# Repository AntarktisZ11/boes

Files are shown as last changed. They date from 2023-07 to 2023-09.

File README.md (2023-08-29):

# What is this?

This is Bamses Øhlhäfvarstoppur also called Bøs.

TODO Desc. the rules of häfv.

# Why is this?

TODO

# How to build Bøs (Bamses Øhlhäfvarstoppur)

TODO

## Hardware prerequisites

[List of components](./Hardware.md)

Rough cost estimate: 1000-800kr

<details>
<summary>Pico RGB matrix pinout</summary>
<br>
TODO add pinout

</details>

### Main PCB

[Schematic PDF](./docs/pcb-boes-main/boes-schematic.pdf)

[CSV BoM](./docs/pcb-boes-main/BoM/boes-bom.csv)

[Interactive BoM](./docs/pcb-boes-main/BoM/boes-ibom.html) (Download and view in browser.)

#### Top and bottom view of PCB

PCB top-view SVG
PCB bottom-view SVG

### USB-C Power distribution PCB

[Schematic PDF](./docs/pcb-boes-usb-c/boes_usb-c-schematic.pdf)

[CSV BoM](./docs/pcb-boes-usb-c/BoM/boes_usb-c-bom.csv)

[Interactive BoM](./docs/pcb-boes-usb-c/BoM/boes_usb-c-ibom.html) (Download and view in browser.)

#### Top and bottom view of PCB

PCB top-view SVG
PCB bottom-view SVG

### Sensor PCB

[Schematic PDF](./docs/pcb-boes-sensor/boes_sensor-schematic.pdf)

[CSV BoM](./docs/pcb-boes-sensor/BoM/boes_sensor-bom.csv)

[Interactive BoM](./docs/pcb-boes-sensor/BoM/boes_sensor-ibom.html) (Download and view in browser.)

#### Top and bottom view of PCB

PCB top-view SVG
PCB bottom-view SVG

## Software prerequisites

The following tools and libraries are required to compile and flash the Pico.

- Arduino CLI tool (or Arduino IDE, whatever works)
- [Raspberry Pi Pico Arduino core](https://github.com/earlephilhower/arduino-pico)
- Adafruit and Arduino libraries (see below)

## Linux guide

Install Pico Arduino core (if not already prepared):

```bash
# Initialize arduino-cli
arduino-cli config init

# Add Pico url to additional_urls like this:
additional_urls: [https://github.com/earlephilhower/arduino-pico/releases/download/global/package_rp2040_index.json]

# Update index to download rp2040 config
arduino-cli core update-index

# Download Pico cores
arduino-cli core install rp2040:rp204
```

Install the required libraries:

```bash
# Note: 'arduino-cli lib install <library>' installs <library>
# and all its dependencies.

# Adafruit library required to driver the led matrix.
arduino-cli lib install "Adafruit Protomatter"

# Protothread / simulated threads in software to schedule
# timer, display and button controllers.
arduino-cli lib install "ArduinoThread"
```

## Compiling and uploading binary

After the prerequisites are satisfied you should be able to compile and upload the binary to the Pico.

```bash
# Compile and upload binary.
# (Note: For me <serial> was set to /dev/ttyACM0)
arduino-cli compile -u -p <serial> -b rp2040:rp2040:rpipicow display/display.ino
```

# Future improvements

- Separate code into thread classes (e.g. display and web server handling in their own respective class)
- Config file handling for constants/delays/logo (USB mass storage) when plugging the cable (also allow uploading configs on web server site?)
- HTML/CSS file handling (USB mass storage).. not the crude http response way that is currently implemented

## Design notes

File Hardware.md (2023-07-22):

Needed hardware is as follows.

- Raspberry Pi Pico or Pico W
- 3x buttons
    - Start
    - Stop
    - Reset
- Speaker/Buzzer (Has to be loud enough)
- 2x Vibration sensors
    - GX-16-3 connector
    - Sensitivity potentiometer
    - Sensor element (piezo or microphone)
    - May need amplifier.
- USB-C connector, 5V / 2.5A
- IDC-16 connector
- Display power connector/screw terminal
- Display, P*x.x* HUB75 RGB LED
    - Note: P*x.x* is the pixel pitch. P2.5 for desktop (160mm x 80mm), P5 for large screen (320mm x 160mm).

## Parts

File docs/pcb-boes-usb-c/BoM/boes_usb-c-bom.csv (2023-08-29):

Part | Value | Footprint | References | Quantity Per PCB | Farnell Nr | Datasheet
USB_C_Receptacle_USB2.0 | USB_C_Receptacle_USB2.0 | USB_C_Receptacle_GCT_USB4105-xx-A_16P_TopMnt_Horizontal | J1 | 1 |  | https://www.usb.org/sites/default/files/documents/usb_type-c.zip
R | 5k1 | R_0603_1608Metric | R1 R2 | 2 |  | ~

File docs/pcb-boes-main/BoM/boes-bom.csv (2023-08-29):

Part | Value | Footprint | References | Quantity Per PCB | Farnell Nr | Datasheet
Buzzer | Buzzer |  | BZ1 | 1 |  | https://www.farnell.com/datasheets/1504043.pdf
D_Schottky | D_Schottky | D_SMA-SMB_Universal_Handsoldering | D1 | 1 |  | ~
Screw_Terminal_01x02 | +5V External | TerminalBlock_Phoenix_MKDS-1,5-2-5.08_1x02_P5.08mm_Horizontal | J9 | 1 |  | ~
Conn_02x08_Odd_Even | HUB75 Display ctrl | IDC-Header_2x08_P2.54mm_Vertical | J10 | 1 |  | ~
Conn_01x03 | Pot_J | JST_XH_B3B-XH-A_1x03_P2.50mm_Vertical | J4 J6 J7 P4 | 4 |  | ~
Conn_01x02 | SW_A | JST_XH_B2B-XH-A_1x02_P2.50mm_Vertical | J1 J2 J3 J8 P1 P2 P3 P8 | 8 |  | ~
2N7000 | 2N7000 | SOT-23 | Q1 | 1 |  | https://www.vishay.com/docs/70226/70226.pdf
R | R | R_0603_1608Metric | R2 | 1 |  | ~
R | 10k | R_0603_1608Metric | R1 | 1 |  | ~
R_Potentiometer | 10k |  | RV1 | 1 |  | ~
SW_Push | Reset |  | SW3 | 1 |  | ~
SW_Push | Start |  | SW1 | 1 |  | ~
SW_Push | Stop |  | SW2 | 1 |  | ~
PicoW | PicoW | RPi_PicoW_SMD_TH | U1 | 1 |  | https://datasheets.raspberrypi.com/picow/pico-w-datasheet.pdf

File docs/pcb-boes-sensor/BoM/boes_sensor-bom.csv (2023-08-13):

Part | Value | Footprint | References | Quantity Per PCB | Farnell Nr | Datasheet
C | 100n | C_0603_1608Metric | C1 C2 C4 | 3 |  | ~
C | 1u | C_0603_1608Metric | C3 | 1 |  | ~
D | 1N4148 | D_MiniMELF | D2 | 1 |  | ~
BAV99 | BAV99 | SOT-23 | D1 | 1 |  | https://assets.nexperia.com/documents/data-sheet/BAV99_SER.pdf
R | R | R_0603_1608Metric | R1 R2 | 2 |  | ~
R | 100k | R_0603_1608Metric | R4 | 1 |  | ~
R_Variable | R_Variable | R_0603_1608Metric | R3 | 1 |  | ~
LM358 | LM358 | SOIC-8_3.9x4.9mm_P1.27mm | U1 | 1 |  | http://www.ti.com/lit/ds/symlink/lm2904-n.pdf
Crystal | Piezo | SolderWire-0.1sqmm_1x02_P3.6mm_D0.4mm_OD1mm_Relief | Y1 | 1 |  | ~

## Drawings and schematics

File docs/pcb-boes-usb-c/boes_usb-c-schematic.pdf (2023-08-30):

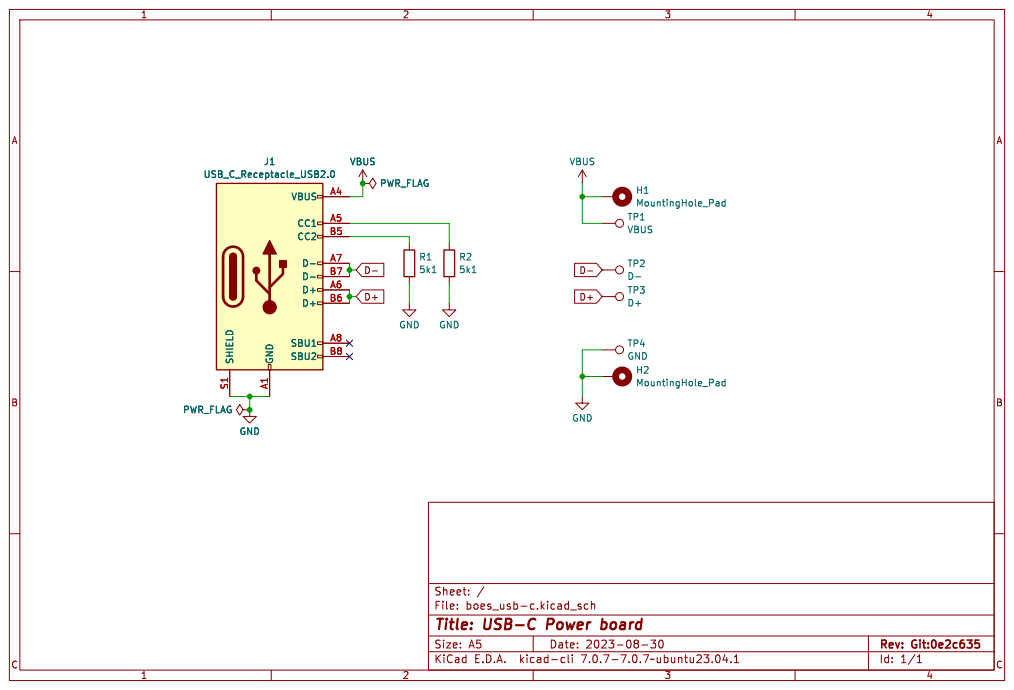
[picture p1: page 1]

Id: 1/1 Title: USB-C Power board

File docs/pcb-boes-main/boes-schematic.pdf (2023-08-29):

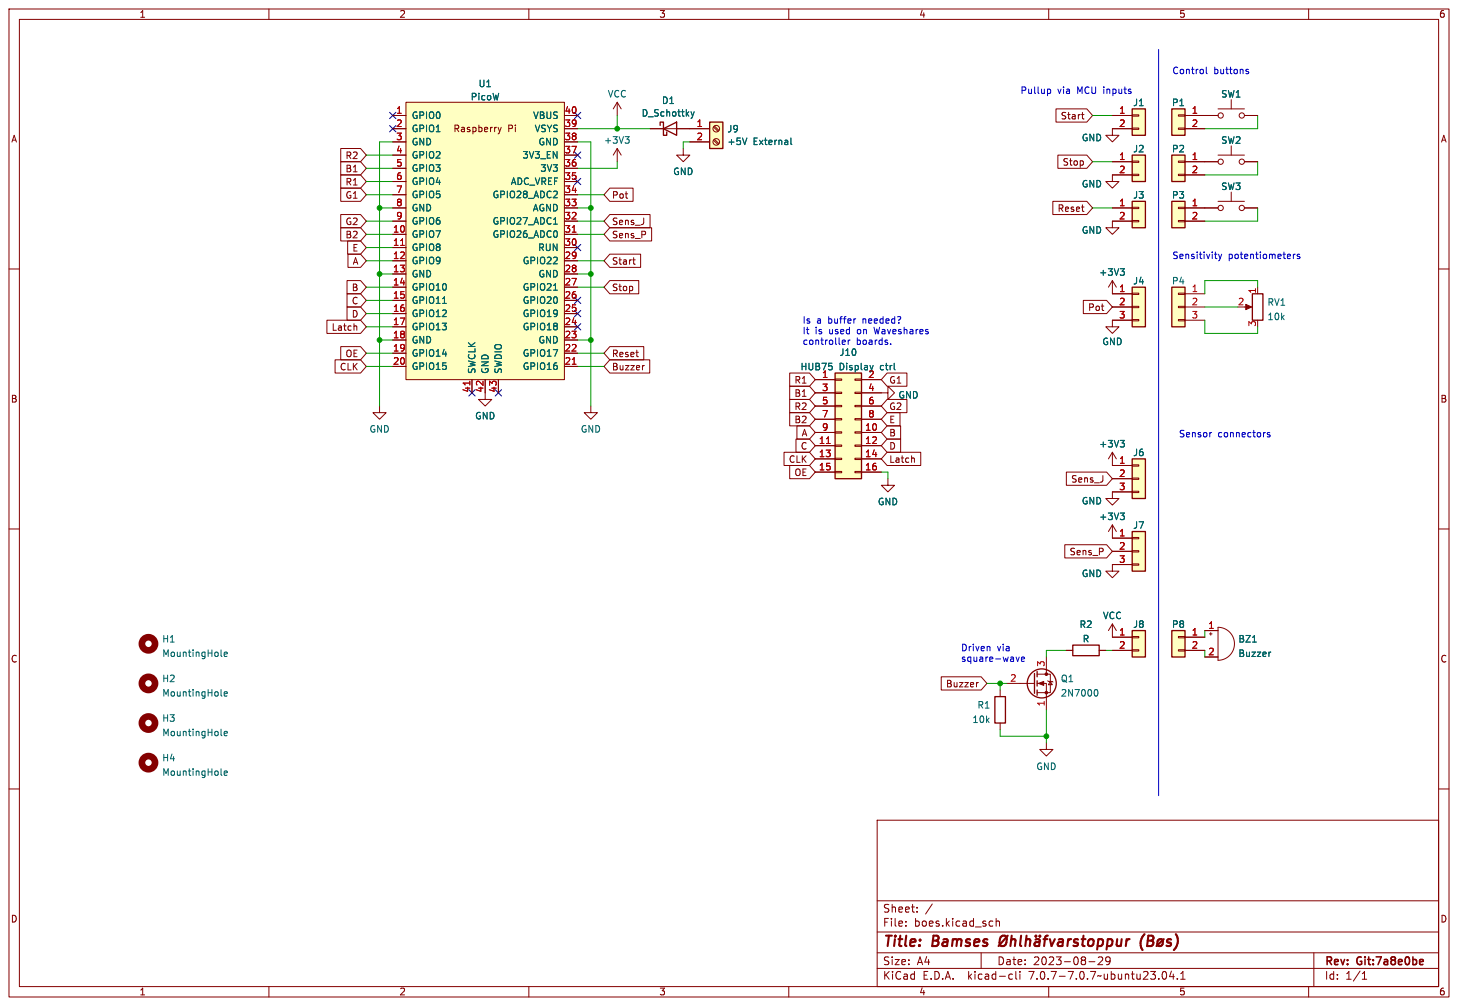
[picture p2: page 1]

Pullup via MCU inputs GND GND

Is a buffer needed?
It is used on Waveshares

Id: 1/1 Title: Bamses þÿØhlhäfvarstoppur þÿ(Bøs) File: boes.kicad_sch Sheet: /

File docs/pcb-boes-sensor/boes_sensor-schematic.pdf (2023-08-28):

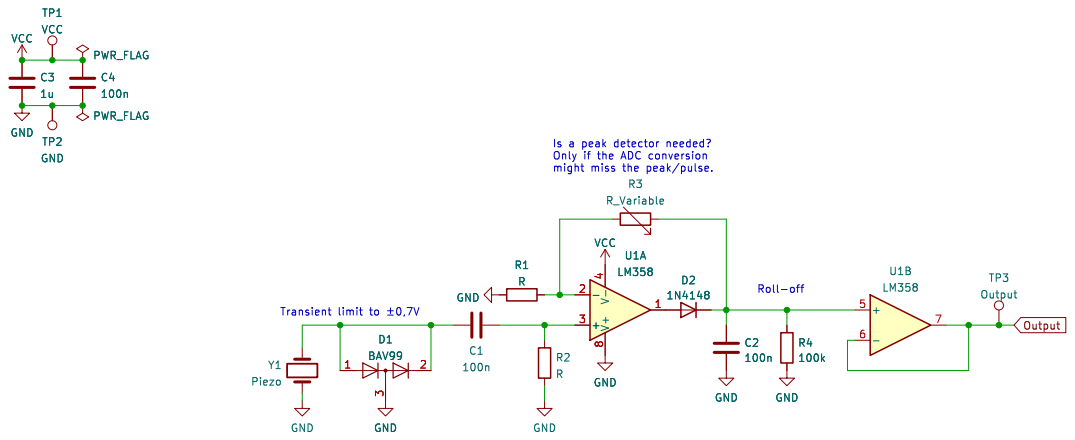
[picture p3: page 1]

Id: 1/1 Title: File: boes_sensor.kicad_sch Sheet: /

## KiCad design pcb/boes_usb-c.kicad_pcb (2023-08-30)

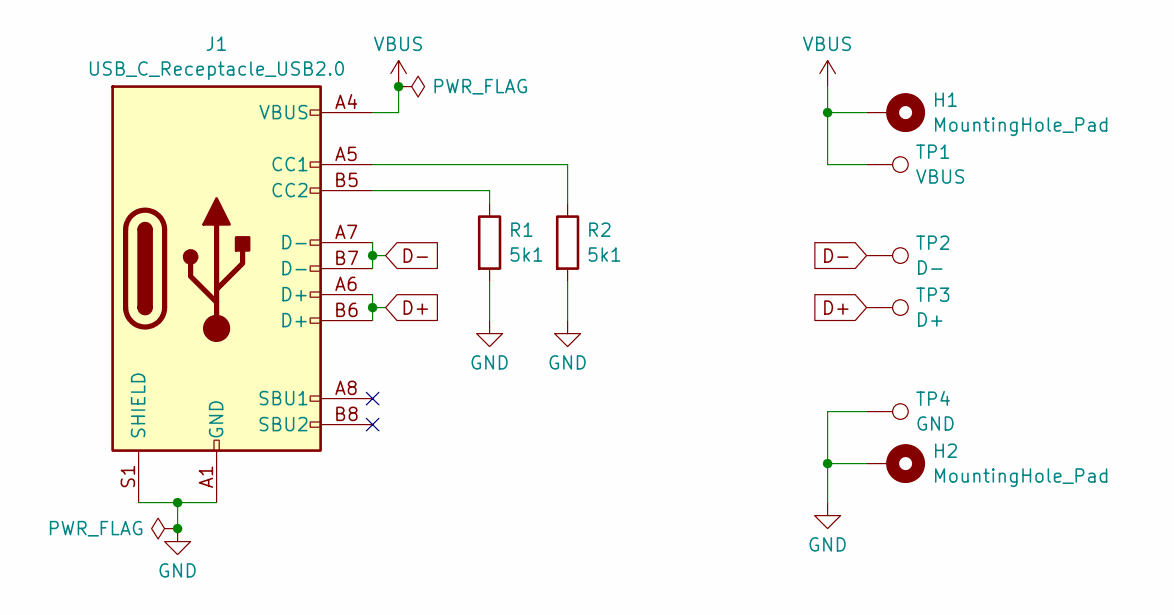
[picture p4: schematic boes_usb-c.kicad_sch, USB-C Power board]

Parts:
H1, H2: MountingHole_Pad; MountingHole_3.2mm_M3_Pad_TopOnly
J1: USB_C_Receptacle_USB2.0; USB_C_Receptacle_GCT_USB4105-xx-A_16P_TopMnt_Horizontal
R1, R2: 5k1; R_0603_1608Metric
TP1: VBUS; SolderWire-0.5sqmm_1x01_D0.9mm_OD2.1mm_Relief
TP2: D-; SolderWire-0.1sqmm_1x01_D0.4mm_OD1mm_Relief
TP3: D+; SolderWire-0.1sqmm_1x01_D0.4mm_OD1mm_Relief
TP4: GND; SolderWire-0.5sqmm_1x01_D0.9mm_OD2.1mm_Relief

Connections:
D+: J1.A6 (D+), J1.B6 (D+), TP3.1
D-: J1.A7 (D-), J1.B7 (D-), TP2.1
GND: H2.1, J1.A1 (GND), J1.A12 (GND), J1.B1 (GND), J1.B12 (GND), J1.S1 (SHIELD), R1.2, R2.2, TP4.1
unnamed: J1.A5 (CC1), R2.1
unnamed: J1.B5 (CC2), R1.1
VBUS: H1.1, J1.A4 (VBUS), J1.A9 (VBUS), J1.B4 (VBUS), J1.B9 (VBUS), TP1.1

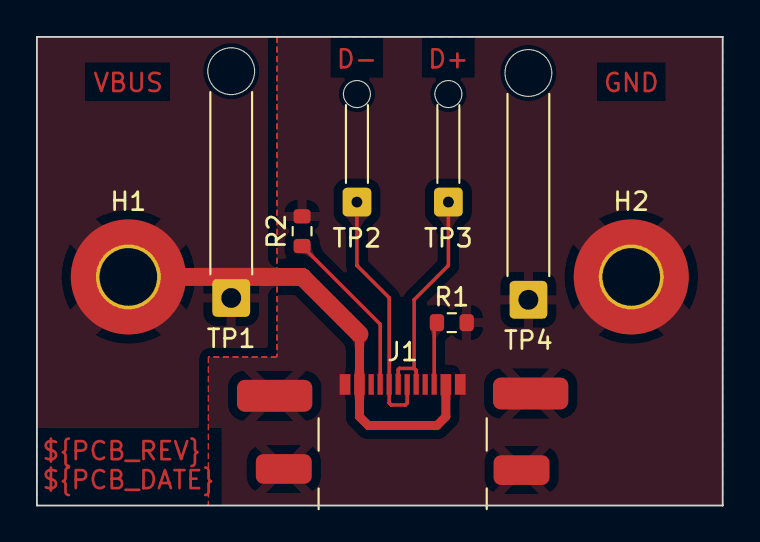
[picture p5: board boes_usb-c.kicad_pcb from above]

Board: 2 copper layers, 38.1 x 26.0 mm, 9 parts (0 on the bottom side), 6 nets.

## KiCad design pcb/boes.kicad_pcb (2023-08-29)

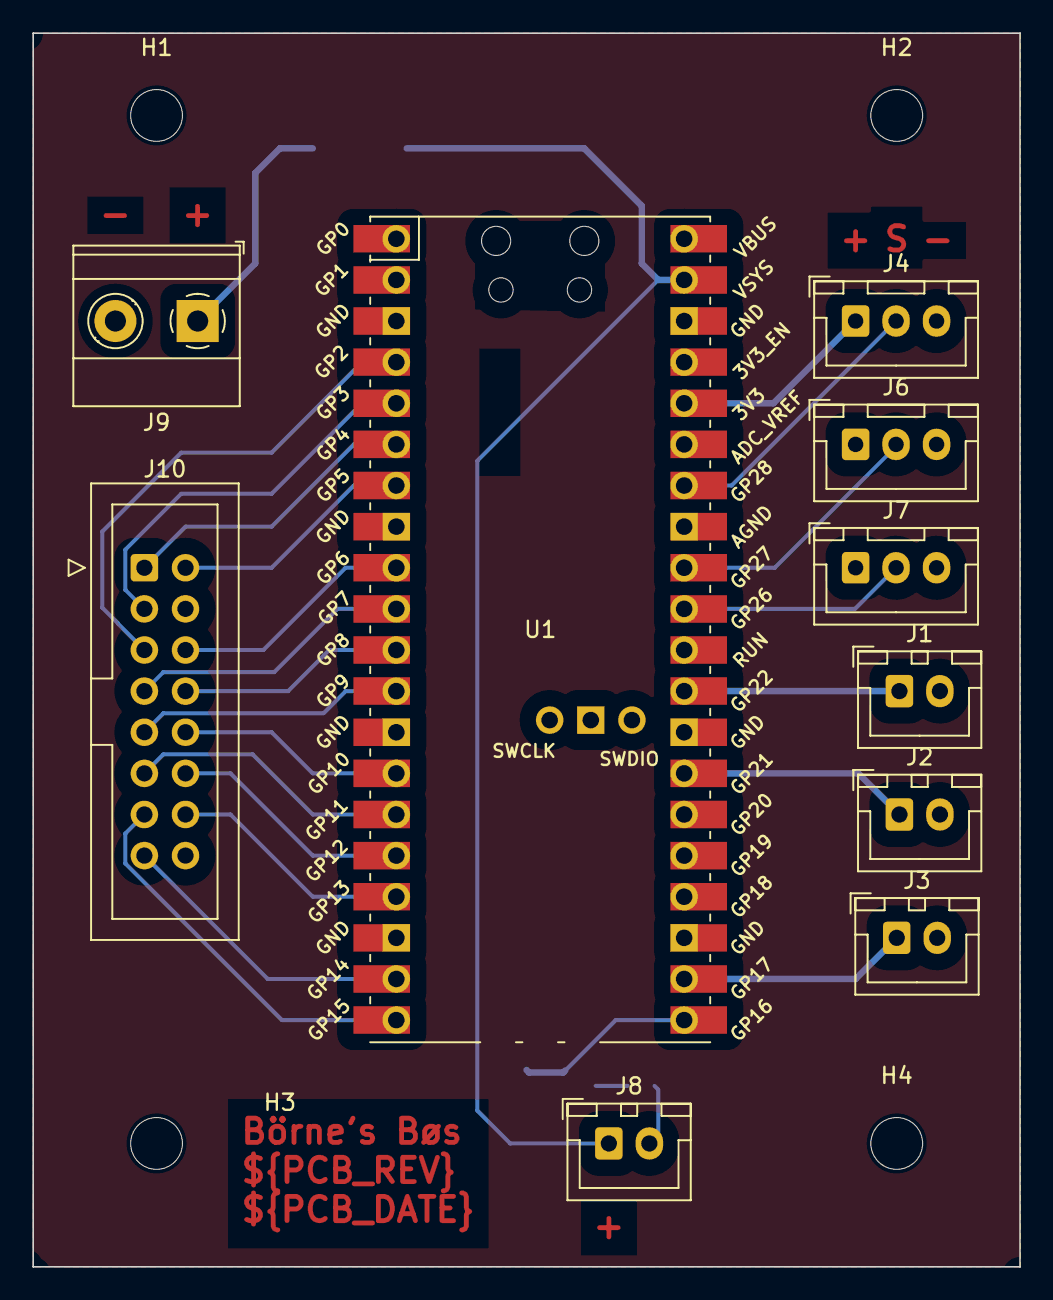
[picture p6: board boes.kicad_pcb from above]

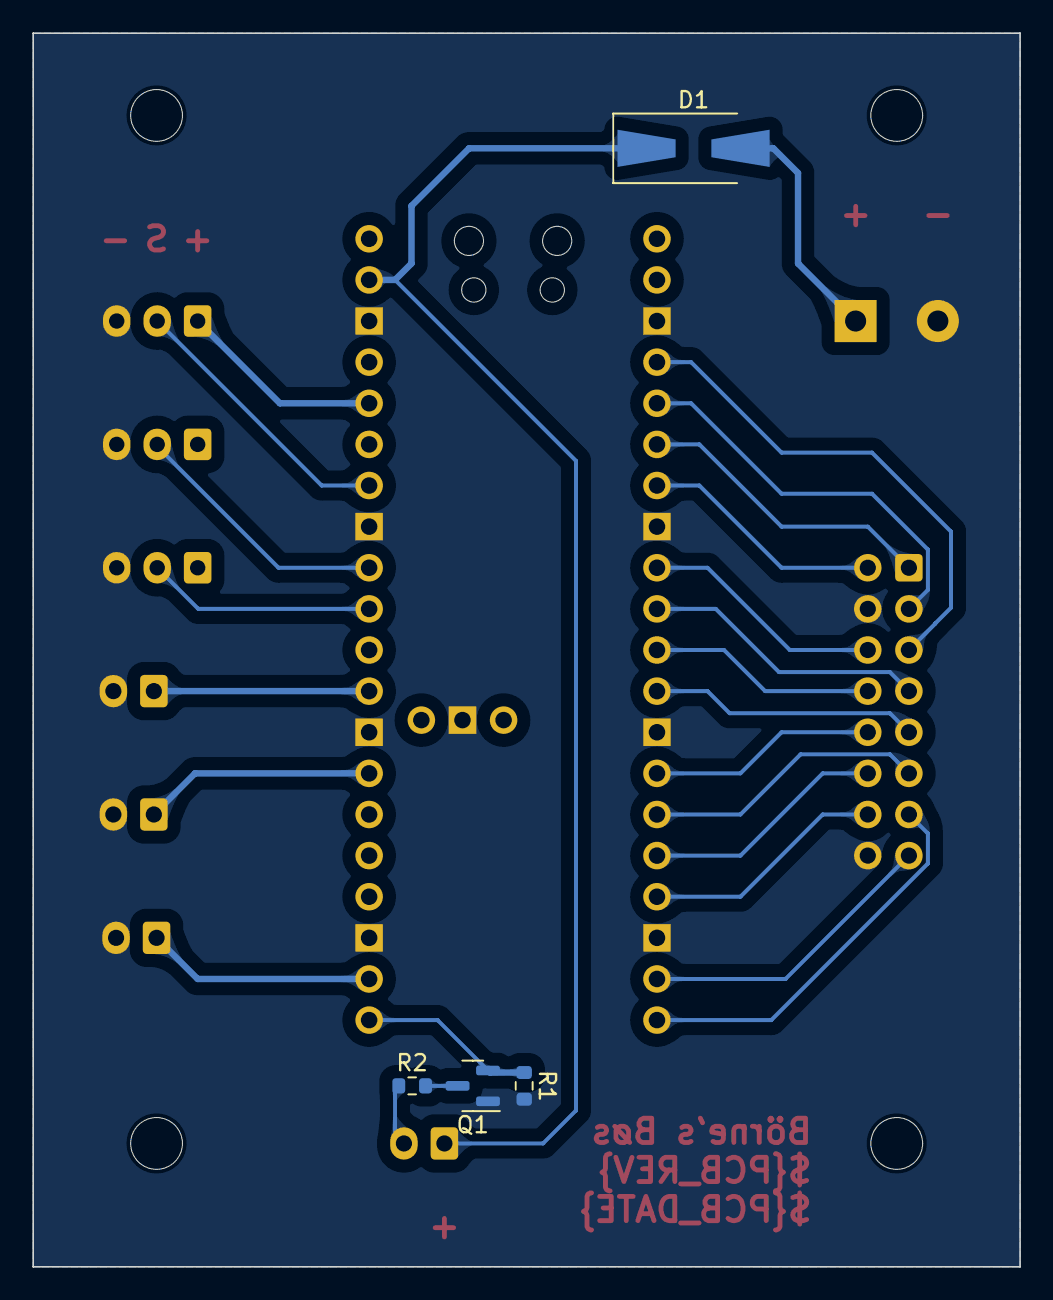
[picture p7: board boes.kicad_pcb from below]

Board: 2 copper layers, 61.0 x 76.2 mm, 18 parts (4 on the bottom side), 27 nets.

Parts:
D1: D_Schottky; D_SMA-SMB_Universal_Handsoldering
H1, H2, H3, H4: MountingHole; MountingHole_3.2mm_M3
J1: SW_A; JST_XH_B2B-XH-A_1x02_P2.50mm_Vertical
J2: SW_B; JST_XH_B2B-XH-A_1x02_P2.50mm_Vertical
J3: SW_C; JST_XH_B2B-XH-A_1x02_P2.50mm_Vertical
J4: Pot_J; JST_XH_B3B-XH-A_1x03_P2.50mm_Vertical
J6: Sens_J; JST_XH_B3B-XH-A_1x03_P2.50mm_Vertical
J7: Sens_P; JST_XH_B3B-XH-A_1x03_P2.50mm_Vertical
J8: Buzzer; JST_XH_B2B-XH-A_1x02_P2.50mm_Vertical
J9: +5V External; TerminalBlock_Phoenix_MKDS-1,5-2-5.08_1x02_P5.08mm_Horizont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
J10: HUB75 Display ctrl; IDC-Header_2x08_P2.54mm_Vertical
Q1: 2N7000; SOT-23
R1: 10k; R_0603_1608Metric
R2: R; R_0603_1608Metric
U1: PicoW; RPi_PicoW_SMD_TH

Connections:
+3V3: J4.1, J6.1, J7.1, U1.36 (3V3)
A: J10.9, U1.12 (GPIO9)
B: J10.10, U1.14 (GPIO10)
B1: J10.3, U1.5 (GPIO3)
B2: J10.7, U1.10 (GPIO7)
Buzzer: Q1.2 (G), R1.1, U1.21 (GPIO16)
C: J10.11, U1.15 (GPIO11)
CLK: J10.13, U1.20 (GPIO15)
D: J10.12, U1.16 (GPIO12)
E: J10.8, U1.11 (GPIO8)
G1: J10.2, U1.7 (GPIO5)
G2: J10.6, U1.9 (GPIO6)
GND: J1.2, J2.2, J3.2, J4.3, J6.3, J7.3, J9.2, J10.4, J10.16, Q1.1 (S), R1.2, U1.3 (GND), U1.8 (GND), U1.13 (GND), U1.18 (GND), U1.23 (GND), U1.28 (GND), U1.33 (AGND), U1.38 (GND), U1.42 (GND)
Latch: J10.14, U1.17 (GPIO13)
unnamed: D1.2 (A), J9.1
unnamed: J8.2, R2.1
unnamed: Q1.3 (D), R2.2
OE: J10.15, U1.19 (GPIO14)
Pot: J4.2, U1.34 (GPIO28_ADC2)
R1: J10.1, U1.6 (GPIO4)
R2: J10.5, U1.4 (GPIO2)
Reset: J3.1, U1.22 (GPIO17)
Sens_J: J6.2, U1.32 (GPIO27_ADC1)
Sens_P: J7.2, U1.31 (GPIO26_ADC0)
Start: J1.1, U1.29 (GPIO22)
Stop: J2.1, U1.27 (GPIO21)
VCC: D1.1 (K), J8.1, U1.39 (VSYS)

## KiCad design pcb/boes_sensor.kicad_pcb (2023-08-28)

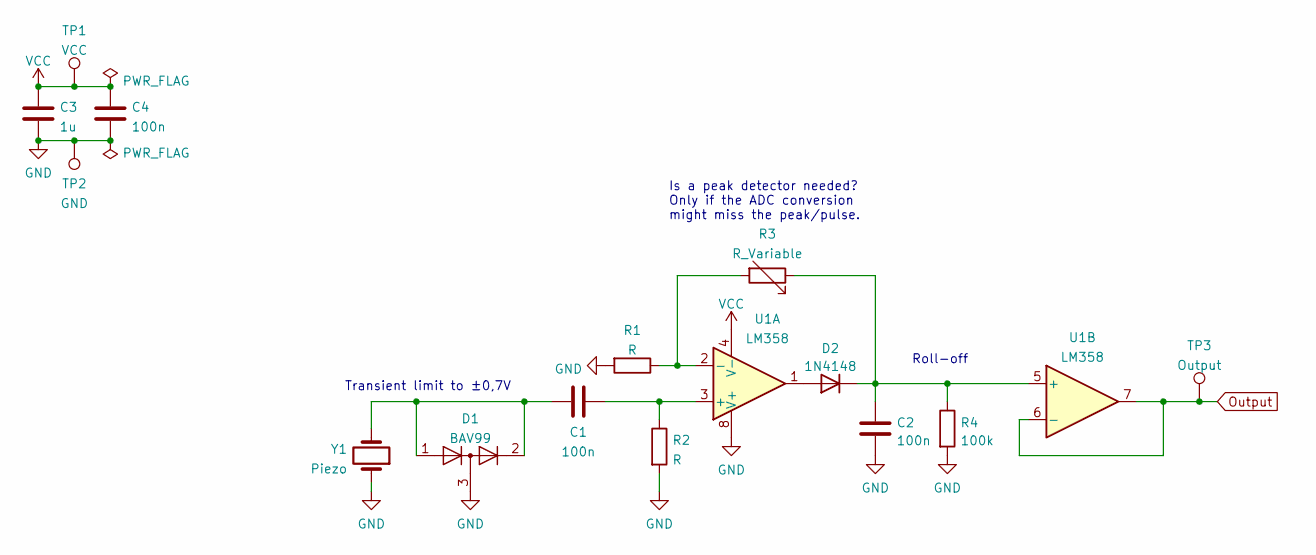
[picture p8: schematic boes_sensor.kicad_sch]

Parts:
C1, C2, C4: 100n; C_0603_1608Metric
C3: 1u; C_0603_1608Metric
D1: BAV99; SOT-23
D2: 1N4148; D_MiniMELF
R1, R2: R; R_0603_1608Metric
R3: R_Variable; R_0603_1608Metric
R4: 100k; R_0603_1608Metric
TP1: VCC; SolderWire-0.25sqmm_1x01_D0.65mm_OD1.7mm_Relief
TP2: GND; SolderWire-0.25sqmm_1x01_D0.65mm_OD1.7mm_Relief
TP3: Output; SolderWire-0.25sqmm_1x01_D0.65mm_OD1.7mm_Relief
U1: LM358; SOIC-8_3.9x4.9mm_P1.27mm
Y1: Piezo; SolderWire-0.1sqmm_1x02_P3.6mm_D0.4mm_OD1mm_Relief

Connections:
GND: C2.2, C3.2, C4.2, D1.3 (K), R1.2, R2.2, R4.2, TP2.1, U1.8 (V+), Y1.1
unnamed: C1.1, D1.1 (K), D1.2 (A), Y1.2
unnamed: C1.2, R2.1, U1.3 (+)
unnamed: C2.1, D2.1 (K), R3.1, R4.1, U1.5 (+)
unnamed: D2.2 (A), U1.1
unnamed: R1.1, R3.2, U1.2 (-)
Output: TP3.1, U1.6 (-), U1.7
VCC: C3.1, C4.1, TP1.1, U1.4 (V-)

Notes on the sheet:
Transient limit to ±0,7V
Is a peak detector needed? Only if the ADC conversion might miss the peak/pulse.
Roll-off

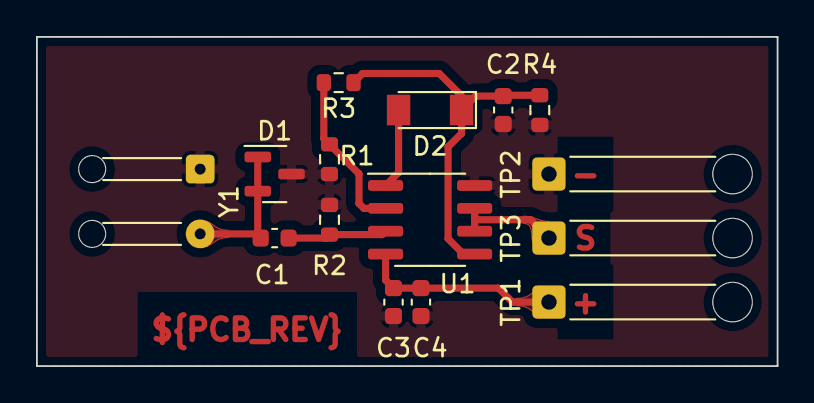
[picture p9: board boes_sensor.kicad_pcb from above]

Board: 2 copper layers, 41.1 x 18.3 mm, 15 parts (0 on the bottom side), 8 nets.

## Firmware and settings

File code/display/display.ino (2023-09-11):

#include <Adafruit_Protomatter.h>
#include <Fonts/FreeSerifBold9pt7b.h>
#include <Thread.h>
#include <StaticThreadController.h>
#include <WiFi.h>
#include "timer.h"
#include "pico/stdlib.h"
#include "pico/cyw43_arch.h"  
#include "logo.h"

// Color definitions used for setting text and background color
#define BLACK    0x0000
#define RED      0xF800
#define ORANGE   0xF324
#define YELLOW   0xFF00
#define GREEN    0x07E0
#define BLUE     0x00FF
#define WHITE    0xFFFF

// Display controller pins
uint8_t rgbPins[]  = {4, 5, 3, 2, 6, 7};
uint8_t addrPins[] = {9, 10, 11, 12, 8};
uint8_t clockPin   = 15;
uint8_t latchPin   = 13;
uint8_t oePin      = 14;

// Button/input pins
uint8_t startBtnPin = 22;           // Button that triggers a timer.start() call if triggered
uint8_t stopBtnPin = 21;            // Button that triggers a timer.stop() call if triggered
uint8_t resetBtnPin = 17;           // Button that triggers a timer.reset() call if triggered
uint8_t sensPot = 28;               // Potentiometer that controls the sensitivity of the vibration sensor
uint8_t judgeVibSensor = 27;        // Vibration sensor that triggers a timer.stop() call if triggered
uint8_t participantVibSensor = 26;  // Vibration sensor that triggers a timer.start() call if triggered
uint8_t buzzer = 16;

Adafruit_Protomatter matrix(
  64,          // Matrix width in pixels
  6,           // Bit depth -- 6 here provides maximum color options
  1, rgbPins,  // # of matrix chains, array of 6 RGB pins for each
  4, addrPins, // # of address pins (height is inferred), array of pins
  clockPin, latchPin, oePin, // Other matrix control pins
  true);       // HERE IS THE MAGIC FOR DOUBLE-BUFFERING!

int16_t  textX = matrix.width(), // Current text position (X)
         textY,                  // Current text position (Y)
         textMin,                // Text pos. (X) when scrolled off left edge
         hue = 0;
char     str[8];                // Buffer to hold timer text "XXX:YYY\0"

Timer timer;
long buzzer_timestamp = 0;
int start_grace_period_us = 1500000; // 1.5 sec start grace period

int port = 80;
char ssid[] = "Bamses Øhlhäfvarstoppur";
char pass[] = "test1234";
int status = WL_IDLE_STATUS;
WiFiServer server(port);

String httpRequest;

Thread timerThread = Thread();
Thread displayThread = Thread();
Thread wifiThread = Thread();
Thread buzzerThread = Thread();
StaticThreadController<4> controller (&timerThread, &displayThread, &wifiThread, &buzzerThread);

void setup(void) {
  Serial.begin(115200);

  // Initialize matrix...
  ProtomatterStatus status = matrix.begin();
  Serial.print("Protomatter begin() status: ");
  Serial.println((int)status);
  
  if(status != PROTOMATTER_OK) {
    // DO NOT CONTINUE if matrix setup encountered an error.
    Serial.println("Matrix error occurred.. cannot continue");
    while(true);
  }

  // TODO Maybe change font as adjacent zeroes touch each other
  matrix.setFont(&FreeSerifBold9pt7b); // Use nice bitmap font
  matrix.setTextColor(0xFFFF);         // White
  matrix.setRotation(0);
  int16_t  x1, y1;
  uint16_t w, h;
  sprintf(str, "%s:%s", timer.sec_counter, timer.ms_counter); // Get initial text to get bounds
  matrix.getTextBounds(str, 0, 0, &x1, &y1, &w, &h);
  textX = matrix.width() / 2 - (x1 + w / 2); // Center text horizontally
  textY = matrix.height() / 2 - (y1 + h / 2); // Center text vertically

  pinMode(startBtnPin, INPUT_PULLUP);
  pinMode(stopBtnPin, INPUT_PULLUP);
  pinMode(resetBtnPin, INPUT_PULLUP);
  pinMode(buzzer, OUTPUT);

  timerThread.onRun(updateTimer);
  displayThread.onRun(updateDisplay);
  wifiThread.onRun(updateWifi);
  buzzerThread.onRun(updateBuzzer);

  timerThread.setInterval(1); // update every 1ms
  displayThread.setInterval(1); // update every 1ms
  wifiThread.setInterval(100); // update every 100ms
  buzzerThread.setInterval(100); // update every 100ms
  
  // check for the WiFi module:
  if (WiFi.status() == WL_NO_MODULE) {
    Serial.println("Communication with WiFi module failed!");
    while (true); // Don't continue
  }

  String fv = WiFi.firmwareVersion();

  if (fv < WIFI_FIRMWARE_LATEST_VERSION) {
    Serial.println("Please upgrade the firmware");
  }

  uint8_t wifiStatus = WiFi.beginAP(ssid, pass);

  if (wifiStatus != WL_CONNECTED) {
    Serial.println("Creating access point failed");
    
    while (true); // Don't continue
  }

  // Startup screen
  matrix.fillScreen(0);
  matrix.setCursor(textX, textY);
  matrix.setTextColor(ORANGE);
  sprintf(str, "Delta"); // Get initial text to get bounds
  matrix.print(str);
  matrix.show();

  // Wait for wifi module to load
  delay(5000); // TODO add constant for this

  server.begin();

  printWiFiStatus();
}

void printWiFiStatus() {

  // print the SSID of the network you're attached to:
  Serial.print("SSID: ");
  Serial.println(WiFi.SSID());

  // print your WiFi shield's IP address:
  IPAddress ip = WiFi.localIP();
  Serial.print("IP Address: ");
  Serial.println(ip);

  // print where to go in a browser:
  Serial.print("To see this page in action, open a browser to http://");
  Serial.println(ip);
}

void loop(void) {
  controller.run();
}

void updateWifi() {
  // Listen for incoming clients
  WiFiClient client = server.available();

  if (client) {

    Serial.println("new client");
    // An http request ends with a blank line
    bool currentLineIsBlank = true;
    while (client.connected()) {
      if (client.available()) {
        char c = client.read();
        
        httpRequest += c;

        // if you've gotten to the end of the line (received a newline
        // character) and the line is blank, the http request has ended,
        // so you can send a reply
        if (c == '\n' && currentLineIsBlank) {

          Serial.println(httpRequest); //print client http request

          // send a standard http response header
          client.println("HTTP/1.1 200 OK");
          client.println("Content-Type: text/html");
          client.println("Connection: close");  // the connection will be closed after completion of the response
          //client.println("Refresh: 5");  // refresh the page automatically every 5 sec
          client.println();
          client.println("<!DOCTYPE HTML>");
          client.println("<html>");
          client.println("<title>Bamses Øhlhäfvarstoppur Admin panel</title>");
          client.println("<h1 style=\"color: #5e9ca0;\">Tidtagarkontrollpanel</h1>");
          client.println("<a href=/?start>START TIMER</a>");
          client.println("<a href=/?stop>STOP TIMER</a>");
          client.println("<a href=/?reset>RESET TIMER</a>");
          client.println("<br>");
          // TODO add timer value
          client.println("</html>");

          break;
        }

        if (c == '\n') {
          // you're starting a new line
          currentLineIsBlank = true;
        } else if (c != '\r') {
          // you've gotten a character on the current line
          currentLineIsBlank = false;
        }
      }
    }

    // give the web browser time to receive the data
    delay(1);

    // close the connection:

    client.stop();
    Serial.println("client disconnected");

    if (httpRequest.indexOf("?start") > 0 ) {
      timer.start();
    }

    if (httpRequest.indexOf("?stop") > 0 ) {
      timer.stop();
    }

    if (httpRequest.indexOf("?reset") > 0 ) {
      timer.reset();
    }

    httpRequest = "";
  }
}

void updateBuzzer() {
  unsigned long buzzer_time_diff = (time_us_64() - timer.timeout_timestamp) / _1_S_IN_US;

  // TODO Create constant for buzzer sound
  if (buzzer_time_diff >= 3) {
    noTone(buzzer);

    // Handles a faulty case where the time_diff is larger than 3 but state is still timeout_1
    return; 
  }

  // Handle buzzer timeout case(s)
  switch (timer.state) {
    case Timeout_1:
      tone(buzzer, 1000);
      break;
    
    case Timeout_2:
      tone(buzzer, 1000);
      break;

    default:
      noTone(buzzer);
  }

}

// Update timer timestamps and input handling
void updateTimer() {
  // Scale sens pot value
  // TODO Add two of these, one for judge and one for participant 
  // make them changeable from the web server
  uint16_t sensPotValue = (1024 * 0.01) + (0.33 * analogRead(sensPot));

  //! Is it worth only updating the relevant sensor instead of both?
  uint16_t judgeVibSensorValue = analogRead(judgeVibSensor);
  uint16_t participantVibSensorValue = analogRead(participantVibSensor);

  timer.run();
  
  // Handle button input handling for timer. (It should always be allowed to control from buttons)
  if (digitalRead(startBtnPin) == LOW) {
    timer.start();
  } else if ((digitalRead(stopBtnPin) == LOW)) {
    timer.stop();
  } else if (digitalRead(resetBtnPin) == LOW) {
    timer.reset();
  }

  switch (timer.state) {
    case Timeout_1:
    case Timeout_2:
    case Pause:
      // Timer should not be started/stopped from VibSensors. Buttons shall be used here instead.
      break;

    default:
      //! This should be fully ignored if it is already started.
      if (judgeVibSensorValue >= sensPotValue) {
        timer.start();
      } else if (participantVibSensorValue >= sensPotValue) { //! This should be checked only if it is currently running.
        // Participant only allowed to stop after 1.5 seconds after judge has started
        if (time_us_64() - timer.start_timestamp >= start_grace_period_us) {
          timer.stop();
        } else {
          Serial.println("Participant not allowed to stop yet");
        }
      }
      break;
  }
}

// Update display text based on input from timer
void updateDisplay() {
  timer.run();
  sprintf(str, "%s:%s", timer.sec_counter, timer.ms_counter);

  matrix.fillScreen(0);
  matrix.setCursor(textX, textY);

  // Timer text default white (init and reset).
  uint16_t textColor;

  switch (timer.state) {
    case Run:
      textColor = GREEN;
      break;

    case Pause:
      textColor = RED;
      break;

    case Timeout_1:
      textColor = YELLOW;
      break;
    
    case Timeout_2:
      textColor = BLUE;
      break;

    default:
      textColor = WHITE;
      break;
  }

  matrix.setTextColor(textColor);
  matrix.print(str);
  matrix.show();
}

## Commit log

2023-07-22 Initial hardware commit
    [boes.kicad_pcb, boes.kicad_sch]
2023-07-22 Add KiCad library submodule
2023-08-05 Separate main board from sensor boards
    [boes.kicad_sch, boes_sensor.kicad_pcb, boes_sensor.kicad_sch]
2023-08-09 Almost finished main board
    [boes.kicad_pcb, boes.kicad_sch]
2023-08-13 Add full PCB documentation dispatch workflow
2023-08-13 Add automatic PCB docs update workflow
2023-08-13 Main PCB ready for final tweaks
    [boes.kicad_pcb, boes.kicad_sch]
2023-08-13 Add finished sensor PCB
    [boes_sensor.kicad_pcb, boes_sensor.kicad_sch]
2023-08-13 Update pcb_change.yaml to trigger on master branch
2023-08-13 Update PCB Documentation
    [boes-bom.csv, boes_sensor-bom.csv]
2023-08-13 Add PCB section to README
2023-08-13 Use teardrop pads for sensor PCB
    [boes_sensor.kicad_pcb, boes_sensor.kicad_sch]
2023-08-13 Add decoupling to sensor VCC rail
    [boes_sensor.kicad_pcb, boes_sensor.kicad_sch]
2023-08-16 Slim main PCB
    [boes.kicad_pcb, boes.kicad_sch]
2023-08-18 Remove need for Pico W
2023-08-23 Fix SCH_REV substitution
    [boes.kicad_sch]
2023-08-24 Revert "Remove need for Pico W"
    This reverts commits:
    d2ab96132ced680a2e2da26c64405593ad7260a6
    dff21f3cf701d05c1464d47412e9ae388ae68376
    [display.ino]
2023-08-28 Upgrade to KiCad 7
    [boes.kicad_pcb, boes.kicad_sch, boes_sensor.kicad_pcb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]
2023-08-28 Add teardrops to main PCB
    [boes.kicad_pcb]
2023-08-29 Repurpose screw terminal as input
    [boes.kicad_pcb, boes.kicad_sch]
2023-08-29 Add teardrops to last change
    [boes.kicad_pcb]
2023-08-29 Add USB-C power board
    [boes_usb-c.kicad_pcb, boes_usb-c.kicad_sch]
2023-08-29 Add USB-C Power distribution PCB to README
2023-08-29 Improve VBUS filled zone
    [boes_usb-c.kicad_pcb]
2023-08-30 Improve strain relief
    [boes_usb-c.kicad_pcb, boes_usb-c.kicad_sch]
2023-09-09 Update pin assignment to match PCB
